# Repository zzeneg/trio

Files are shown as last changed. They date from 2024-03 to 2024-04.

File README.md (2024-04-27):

# trio

Modular unibody keyboard with two VIK modules.

> [!CAUTION]
> This keyboard is designed for minimal vertical spacing (19x16mm). Regular keycaps will not fit, you must print your own - for example my [DES MinY](https://github.com/zzeneg/PseudoMakeMeKeyCapProfiles?tab=readme-ov-file#update-from-zzeneg).
>
> It's created as a cheap prototype to test VIK abilities and modules - all PCBs are under 100x100mm, one-piece case <0.3kg for cheap JLCPCB shipping.
>
> Build process requires a lot of hand-soldering with 0.5mm pitch, you need good tools and experience to do that.
>
> I do not recommend to build it exactly like that, but to use it as inspiration for your projects. Feel free to use and improve KiCad and Fusion 360 source files.

## Features

- **MinY (19x16mm) spacing**
- 36 KS-33 (Gateron Low Profile) keys with hotswap
- central PCB with two independent VIKs, DRV2605L haptic feedback and rotary encoder
- periferal PCBs for keys
- 3D printed case with 1.28" display, Azoteq TPS65 touchpad and 33mm encoder

## Photos

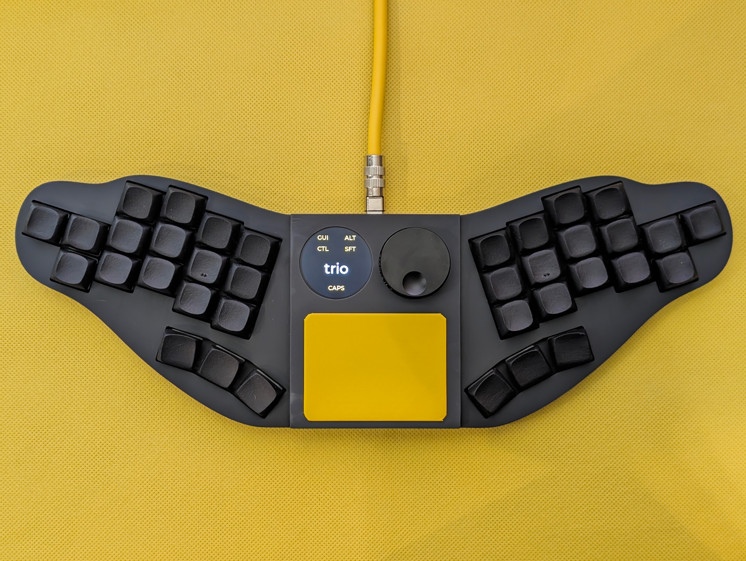
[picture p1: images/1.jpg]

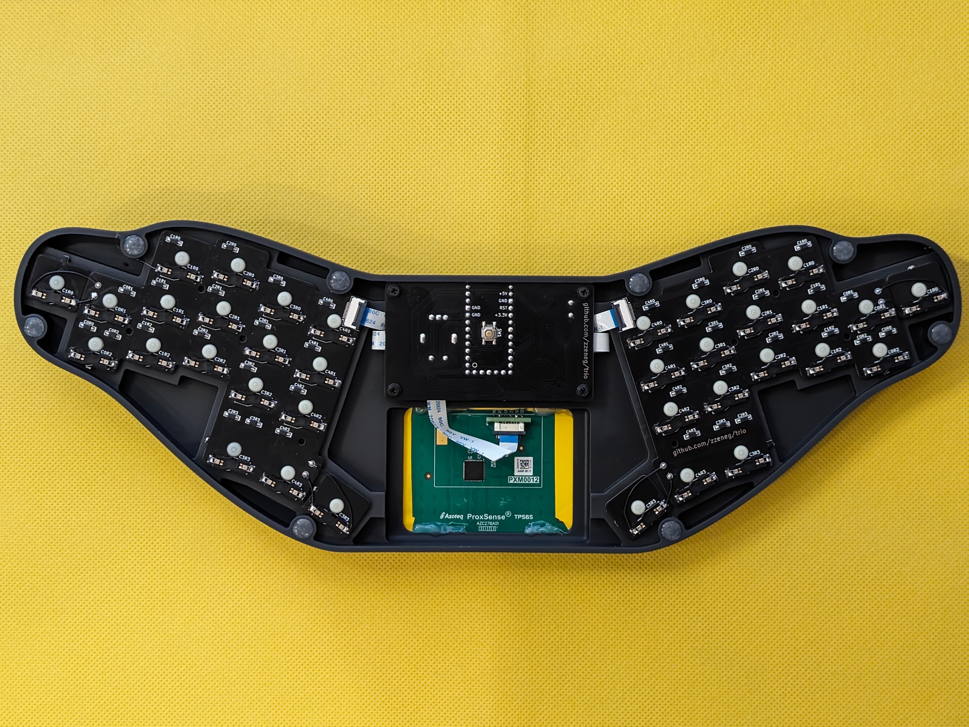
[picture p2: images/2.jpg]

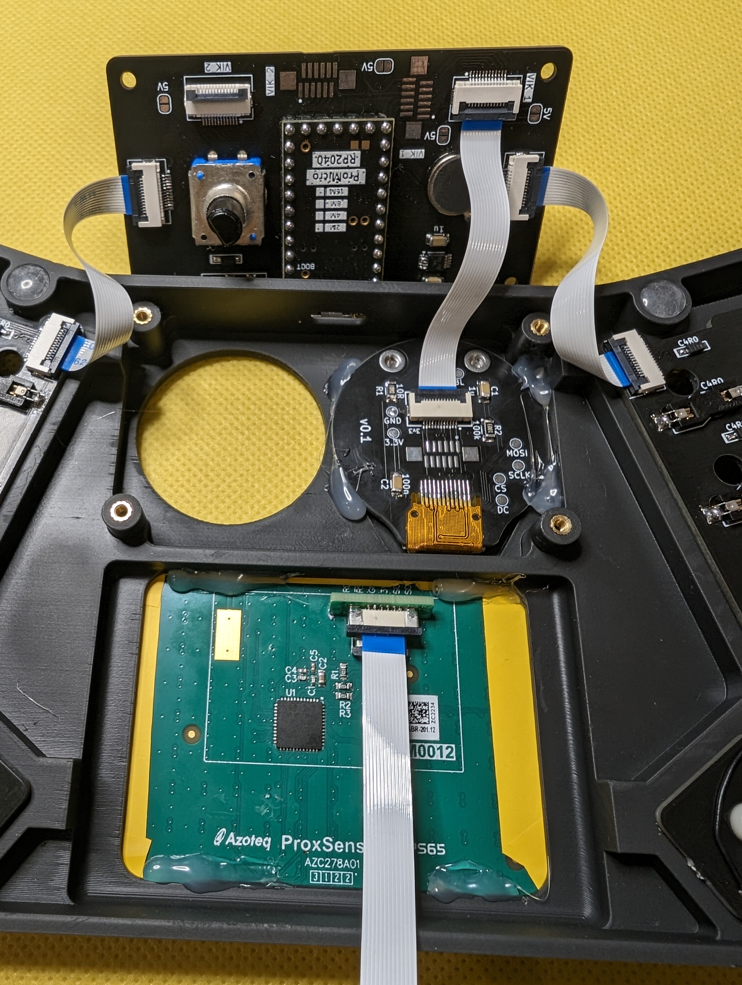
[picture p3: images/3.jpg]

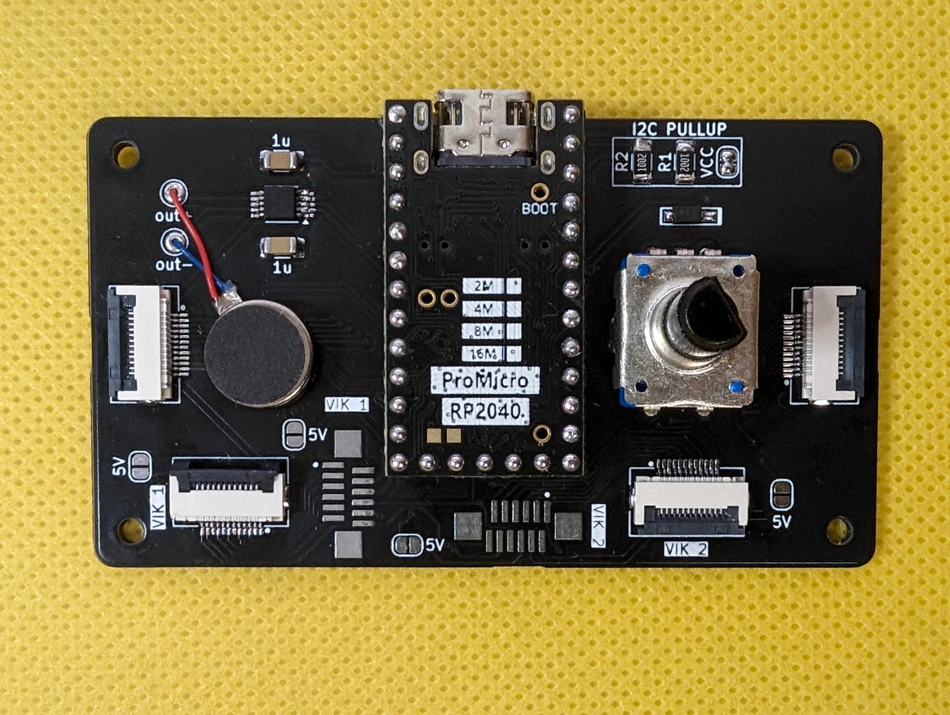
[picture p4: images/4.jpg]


## Gerber files

- [Main PCB](./pcb/production/main.zip)
- [Side PCB](./pcb/production/side.zip)
- Azoteq [VIK adapter](https://github.com/sadekbaroudi/vik/tree/master/pcb/azoteq-tps)
- Display [VIK adapter](https://github.com/zzeneg/vik-display-adapter) - 1.28" round version

## Case files

- [v0.1](./case/main-0.1.stl)
- [v0.2](./case/main-0.1.stl) - higher version, should work but untested

## Firmware

[Companion app](https://github.com/zzeneg/qmk-hid-host) for Raw HID communication. Use `"productId": 2120` for that keyboard.

#### QMK

Please see main `config.h` and `rules.mk` for comments and available options.

- [source code](https://github.com/zzeneg/qmk_firmware/tree/feature/zzeneg/keyboards/trio)
- [pre-compiled files](https://github.com/zzeneg/qmk_firmware/releases/tag/zzeneg)

#### Vial

- [source code](https://github.com/zzeneg/vial-qmk/tree/feature/zzeneg/keyboards/trio)
- [pre-compiled files](https://github.com/zzeneg/vial-qmk/releases/tag/zzeneg)

## Bill of materials

- [PCB](./pcb/production/pcb.zip)
- 36 KS-33 switches
- 36 hotswap sockets for KS-33 switches
- 3D printed case
- Azoteq TPS65 touchpad
- Azoteq [VIK adapter](https://github.com/sadekbaroudi/vik/tree/master/pcb/azoteq-tps)
- Bare 1.28" round [display](https://www.aliexpress.com/item/1005006051175539.html) - **without PCB**
- Display [VIK adapter](https://github.com/zzeneg/vik-display-adapter) - 1.28" round version **+ adapter's BOM**
- Helios-sized (26 GPIOs) [RP2040](https://www.aliexpress.com/item/1005006130019224.html) MCU
- 37 [SMD SOD-123 1N4148](https://www.aliexpress.com/item/1005002882901030.html) diodes
- [Vertical](https://www.aliexpress.com/item/10000000737049.html) and [horizontal](https://www.aliexpress.com/item/4000106123266.html) 12pin FFC/FPC connectors
- 12pin 0.5mm pitch 6cm [FFC cable](https://www.aliexpress.com/item/1005002468369055.html) - **both reverse and forward variants**
- short [EC11 rotary encoder](https://www.aliexpress.com/item/1005002109267228.html)
- 32mm [encoder knob](https://www.aliexpress.com/item/32749414806.html)
- SMD 4x4x1.5mm [push button](https://www.aliexpress.com/item/32802382507.html)
- 4mm [M2 screws with flat head](https://www.aliexpress.com/item/4001248931159.html)
- M2 [heatset inserts](https://www.aliexpress.com/item/1005004624377733.html) - 3mm length, 3.2mm diameter for resin case or 3.5mm for Nylon/PLA
- [7x1.5 legs](https://www.aliexpress.com/item/1005002995402961.html)
- for haptic feedback:
  - DRV2605L motor controller
  - 2 1uF capacitors (SMD 1206 size)
  - 2 4.7kOhm resistors (SMD 1206 size)
  - LRA or ERM [motor](https://docs.qmk.fm/#/feature_haptic_feedback?id=known-supported-hardware)

## Build notes

- side PCBs have two keys that have to be broken off and handwired to correct places (diodes stay on the big part)
- rotary encoder uses GPIO from VIK2, so Azoteq has to be connected to VIK2 port, and display to VIK1. Make sure to bridge solder jumpers on the back.
- cheap ERM motors may not have enough internal resistance, if you motor does not work, try to add 5-10R resistor to it
- see photos for FFC connections

## Development

For proper KiCad setup install my [zzkeeb](https://github.com/zzeneg/zzkeeb/blob/main/README.md#installation) library

## Support

If you like my work and want to support my future designs, please consider [sponsorship](https://github.com/sponsors/zzeneg).

#### Sponsors

Thank you very much for your support!



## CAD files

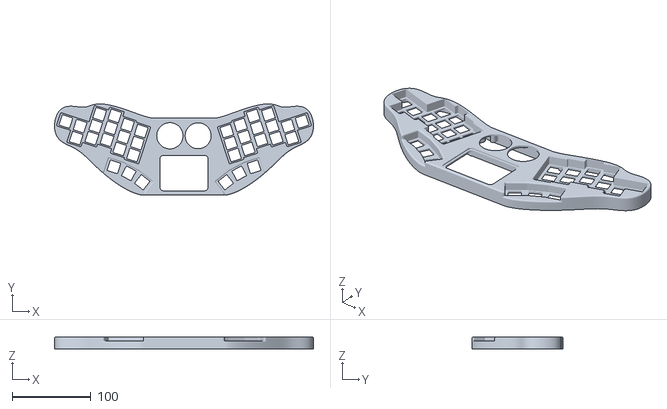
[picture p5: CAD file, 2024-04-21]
case/main-0.2-untested.stl
329.7 x 116.1 x 15.4

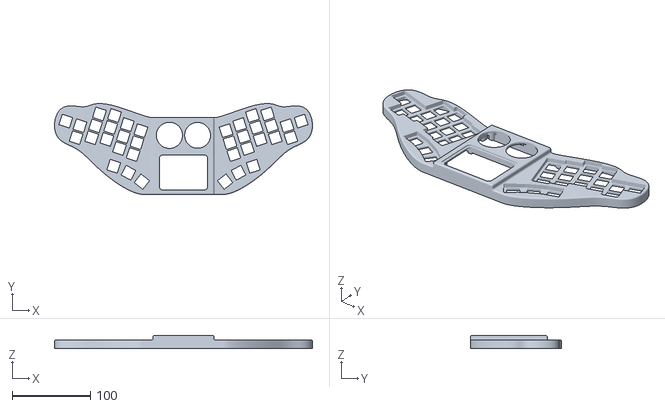
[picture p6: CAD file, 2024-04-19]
case/main-0.1.stl
329.7 x 116.1 x 16.4

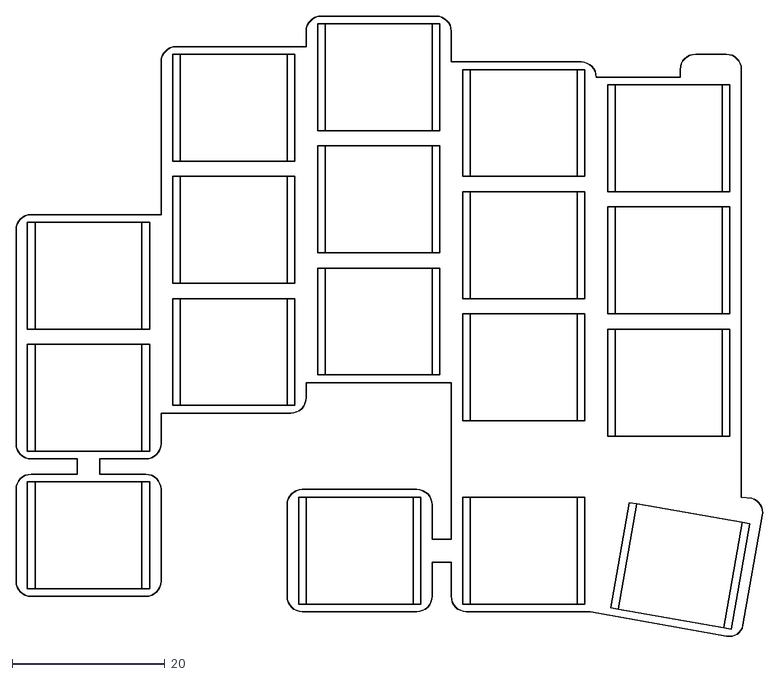
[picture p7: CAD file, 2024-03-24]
pcb/side-Edge_Cuts.dxf
98.0 x 81.3

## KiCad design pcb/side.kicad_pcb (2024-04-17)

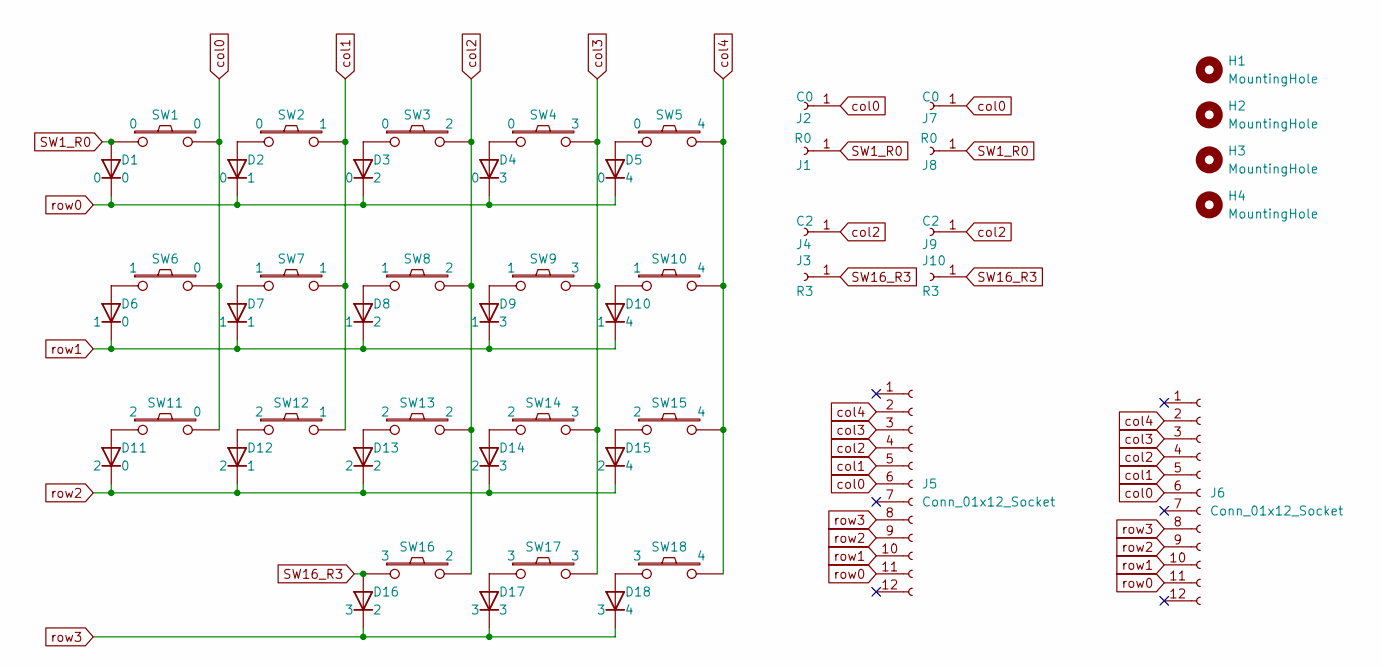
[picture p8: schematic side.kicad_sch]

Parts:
D1, D2, D3, D4, D5, D6, D7, D8, D9, D10, D11, D12, D13, D14, D15, D16, D17, D18: D; Diode_1N4148-SOD123-reversible-flip3d
H1, H2, H3, H4: MountingHole; Hole_M2
J1, J8: R0; TestPoint_THTPad_D1.5mm_Drill0.7mm
J2, J7: C0; TestPoint_THTPad_D1.5mm_Drill0.7mm
J3, J10: R3; TestPoint_THTPad_D1.5mm_Drill0.7mm
J4, J9: C2; TestPoint_THTPad_D1.5mm_Drill0.7mm
J5, J6: Conn_01x12_Socket; Connector_FFC-12pin-0.5mm-horizontal
SW1, SW2, SW3, SW4, SW5, SW6, SW7, SW8, SW9, SW10, SW11, SW12, SW13, SW14, SW15, SW16, SW17, SW18: Switch; Switch_KS-miny-reversible-hotswap-south

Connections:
unnamed: D2.2 (A), SW2.1
unnamed: D3.2 (A), SW3.1
unnamed: D4.2 (A), SW4.1
unnamed: D5.2 (A), SW5.1
unnamed: D6.2 (A), SW6.1
unnamed: D7.2 (A), SW7.1
unnamed: D8.2 (A), SW8.1
unnamed: D9.2 (A), SW9.1
unnamed: D10.2 (A), SW10.1
unnamed: D11.2 (A), SW11.1
unnamed: D12.2 (A), SW12.1
unnamed: D13.2 (A), SW13.1
unnamed: D14.2 (A), SW14.1
unnamed: D15.2 (A), SW15.1
unnamed: D17.2 (A), SW17.1
unnamed: D18.2 (A), SW18.1
SW1_R0: D1.2 (A), J1.1, J8.1, SW1.1
SW16_R3: D16.2 (A), J3.1, J10.1, SW16.1
col0: J2.1, J5.6, J6.6, J7.1, SW1.2, SW6.2, SW11.2
col1: J5.5, J6.5, SW2.2, SW7.2, SW12.2
col2: J4.1, J5.4, J6.4, J9.1, SW3.2, SW8.2, SW13.2, SW16.2
col3: J5.3, J6.3, SW4.2, SW9.2, SW14.2, SW17.2
col4: J5.2, J6.2, SW5.2, SW10.2, SW15.2, SW18.2
row0: D1.1 (K), D2.1 (K), D3.1 (K), D4.1 (K), D5.1 (K), J5.11, J6.11
row1: D6.1 (K), D7.1 (K), D8.1 (K), D9.1 (K), D10.1 (K), J5.10, J6.10
row2: D11.1 (K), D12.1 (K), D13.1 (K), D14.1 (K), D15.1 (K), J5.9, J6.9
row3: D16.1 (K), D17.1 (K), D18.1 (K), J5.8, J6.8

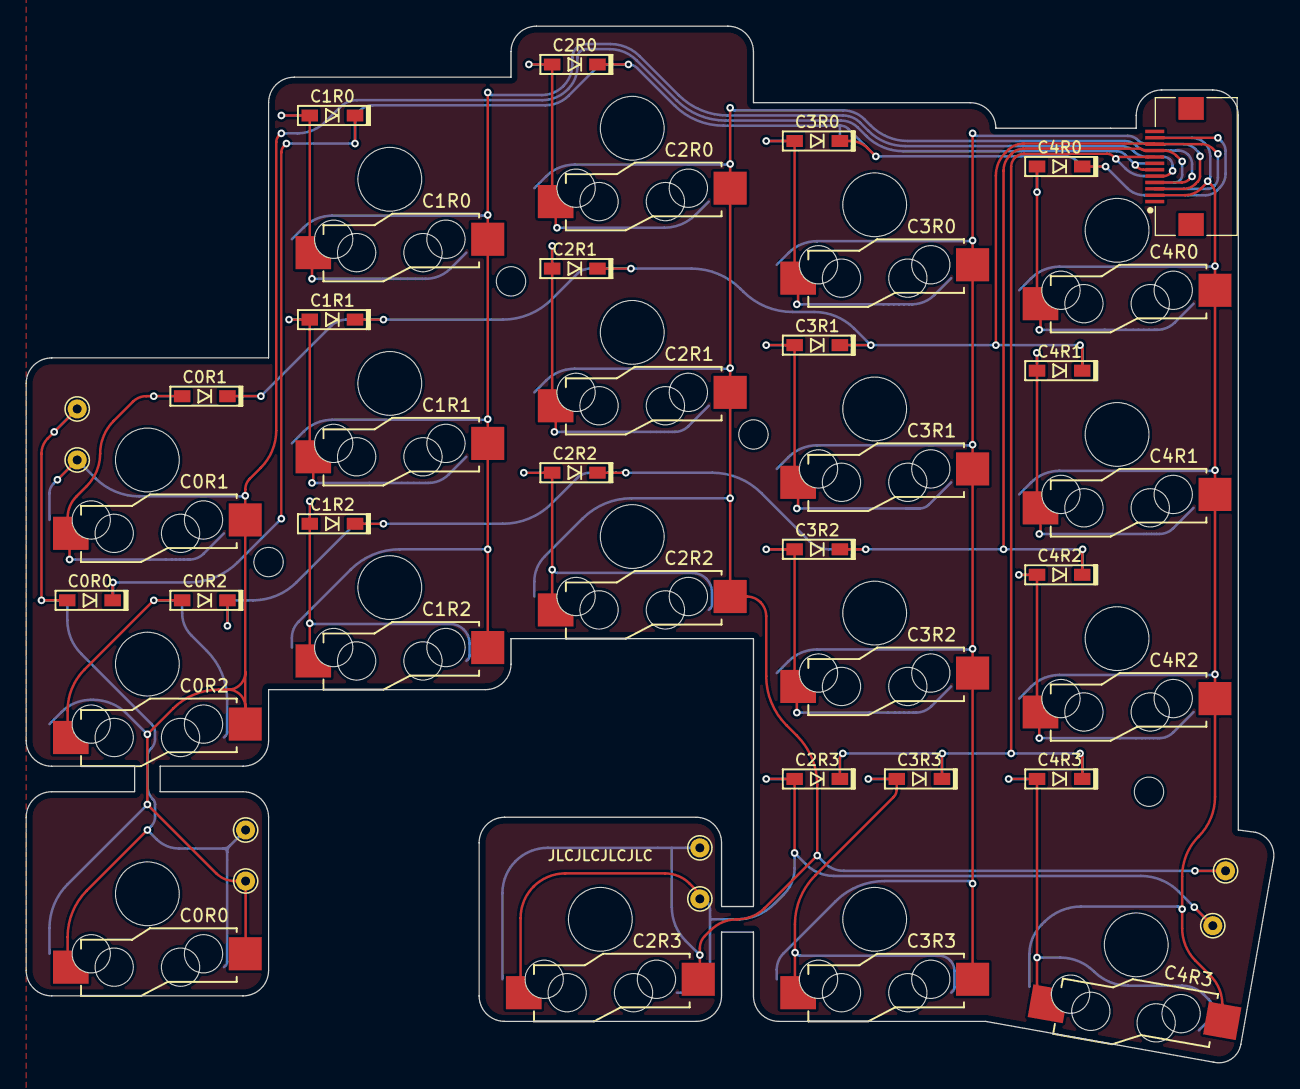
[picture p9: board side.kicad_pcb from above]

Board: 2 copper layers, 97.8 x 81.2 mm, 50 parts (1 on the bottom side), 27 nets.

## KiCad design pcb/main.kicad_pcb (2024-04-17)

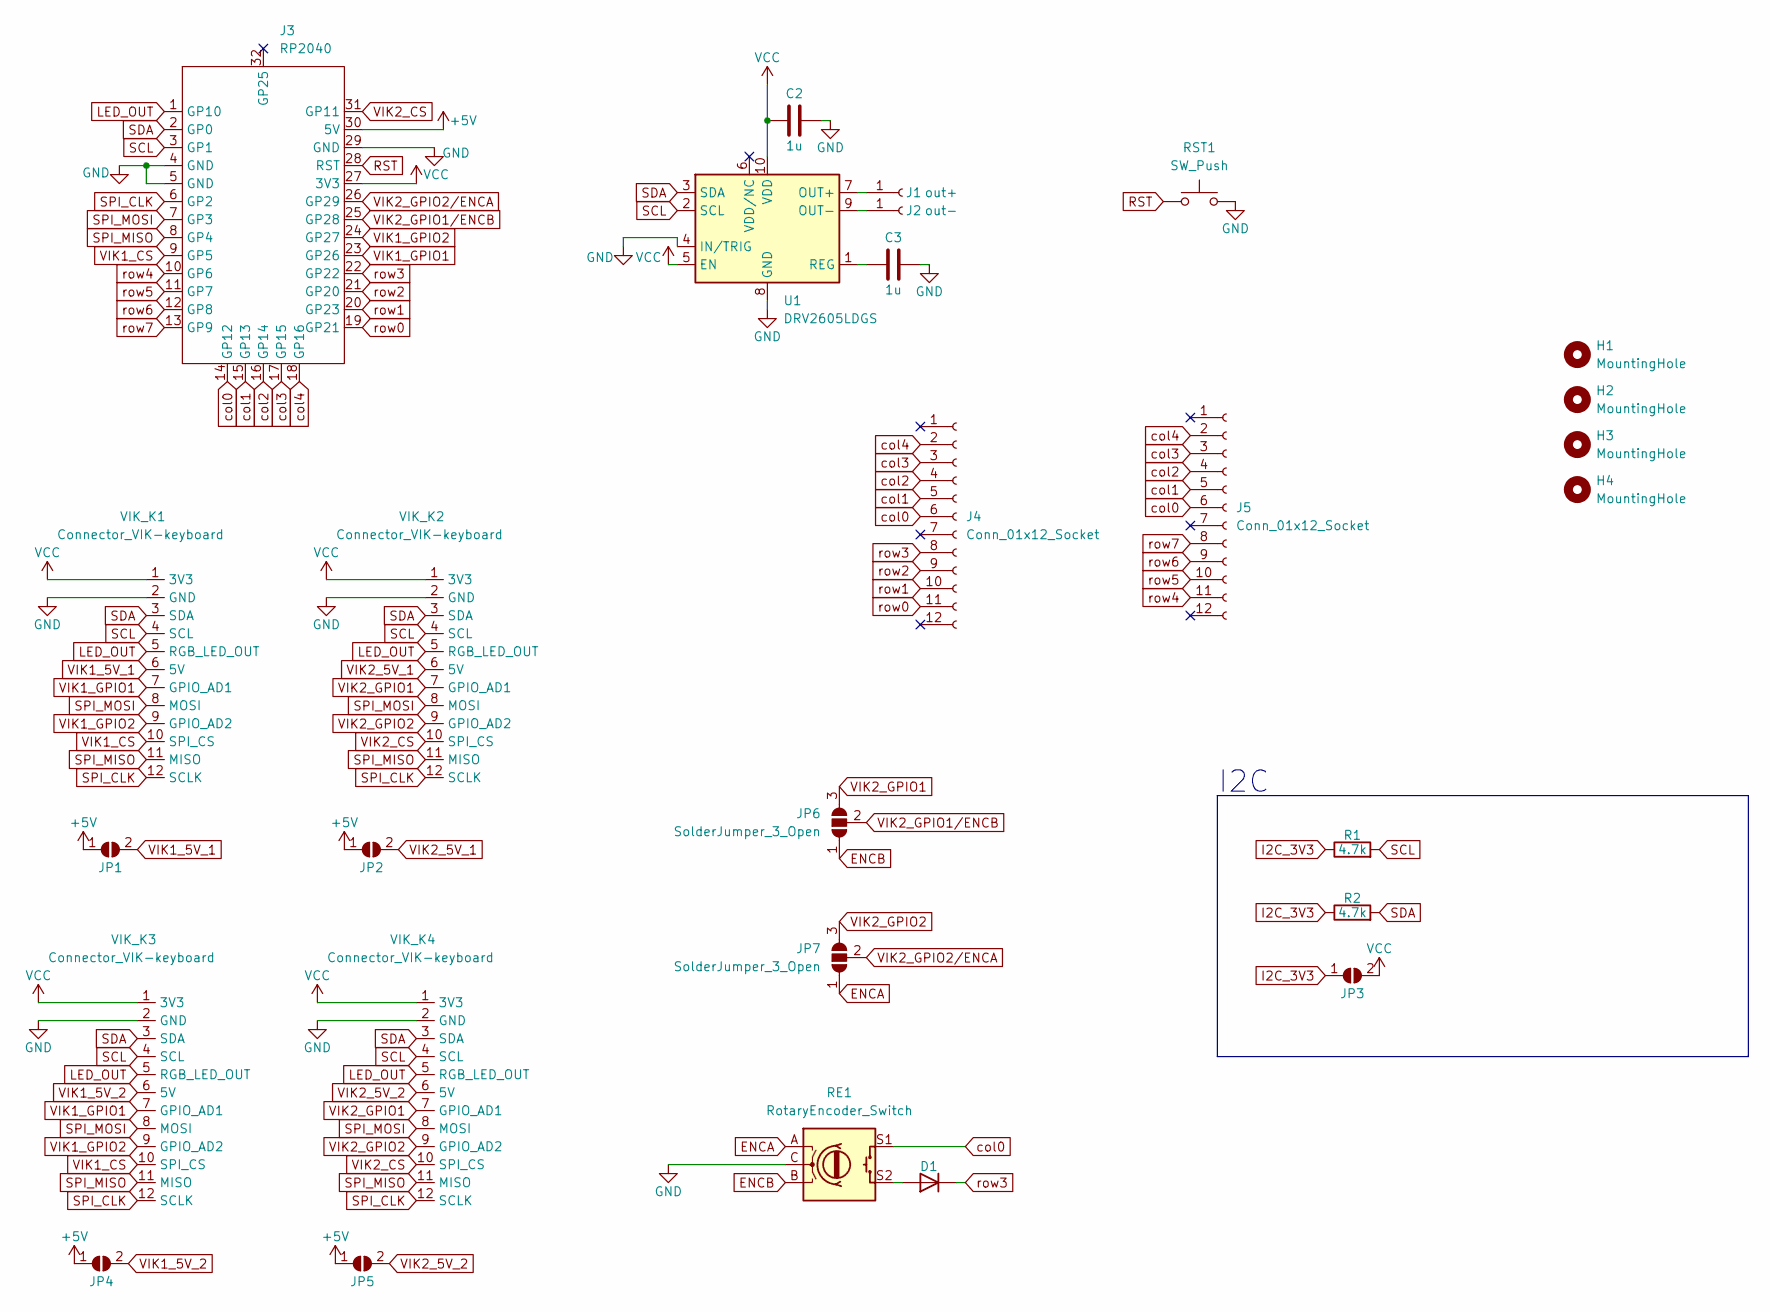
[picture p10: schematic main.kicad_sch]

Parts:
C2, C3: 1u; C_1206_3216Metric
D1: D; Diode_1N4148-SOD123
H1, H2, H3, H4: MountingHole; Hole_M2
J1: out+; TestPoint_THTPad_D2.0mm_Drill1.0mm
J2: out-; TestPoint_THTPad_D2.0mm_Drill1.0mm
J3: RP2040; MCU_rp2040-helios
J4, J5: Conn_01x12_Socket; Connector_FFC-12pin-0.5mm-horizontal
JP1, JP2, JP4, JP5: 5V; SolderJumper-2_P1.3mm_Open_RoundedPad1.0x1.5mm
JP3: VCC; SolderJumper-2_P1.3mm_Open_RoundedPad1.0x1.5mm
JP6, JP7: SolderJumper_3_Open; SolderJumper-3_P1.3mm_Open_Pad1.0x1.5mm
R1, R2: 4.7k; R_1206_3216Metric
RE1: RotaryEncoder_Switch; RotaryEncoder_EC11
RST1: SW_Push; Button_SW_SPST_SKQG_WithoutStem
U1: DRV2605LDGS; VSSOP-10_3x3mm_P0.5mm
VIK_K1, VIK_K2: Connector_VIK-keyboard; Connector_VIK-horizontal-keyboard
VIK_K3, VIK_K4: Connector_VIK-keyboard; Connector_VIK-vertical-keyboard

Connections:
+5V: J3.30 (5V), JP1.1 (A), JP2.1 (A), JP4.1 (A), JP5.1 (A)
ENCA: JP7.1 (A), RE1.A
ENCB: JP6.1 (A), RE1.B
GND: C2.2, C3.2, J3.4 (GND), J3.5 (GND), J3.29 (GND), RE1.C, RST1.2, U1.4 (IN/TRIG), U1.8 (GND), VIK_K1.2 (GND), VIK_K2.2 (GND), VIK_K3.2 (GND), VIK_K4.2 (GND)
I2C_3V3: JP3.1 (A), R1.1, R2.1
LED_OUT: J3.1 (GP10), VIK_K1.5 (RGB_LED_OUT), VIK_K2.5 (RGB_LED_OUT), VIK_K3.5 (RGB_LED_OUT), VIK_K4.5 (RGB_LED_OUT)
unnamed: D1.2 (A), RE1.S2
unnamed: J1.1, U1.7 (OUT+)
unnamed: J2.1, U1.9 (OUT-)
unnamed: C3.1, U1.1 (REG)
RST: J3.28 (RST), RST1.1
SCL: J3.3 (GP1), R1.2, U1.2 (SCL), VIK_K1.4 (SCL), VIK_K2.4 (SCL), VIK_K3.4 (SCL), VIK_K4.4 (SCL)
SDA: J3.2 (GP0), R2.2, U1.3 (SDA), VIK_K1.3 (SDA), VIK_K2.3 (SDA), VIK_K3.3 (SDA), VIK_K4.3 (SDA)
SPI_CLK: J3.6 (GP2), VIK_K1.12 (SCLK), VIK_K2.12 (SCLK), VIK_K3.12 (SCLK), VIK_K4.12 (SCLK)
SPI_MISO: J3.8 (GP4), VIK_K1.11 (MISO), VIK_K2.11 (MISO), VIK_K3.11 (MISO), VIK_K4.11 (MISO)
SPI_MOSI: J3.7 (GP3), VIK_K1.8 (MOSI), VIK_K2.8 (MOSI), VIK_K3.8 (MOSI), VIK_K4.8 (MOSI)
VCC: C2.1, J3.27 (3V3), JP3.2 (B), U1.5 (EN), U1.10 (VDD), VIK_K1.1 (3V3), VIK_K2.1 (3V3), VIK_K3.1 (3V3), VIK_K4.1 (3V3)
VIK1_5V_1: JP1.2 (B), VIK_K1.6 (5V)
VIK1_5V_2: JP4.2 (B), VIK_K3.6 (5V)
VIK1_CS: J3.9 (GP5), VIK_K1.10 (SPI_CS), VIK_K3.10 (SPI_CS)
VIK1_GPIO1: J3.23 (GP26), VIK_K1.7 (GPIO_AD1), VIK_K3.7 (GPIO_AD1)
VIK1_GPIO2: J3.24 (GP27), VIK_K1.9 (GPIO_AD2), VIK_K3.9 (GPIO_AD2)
VIK2_5V_1: JP2.2 (B), VIK_K2.6 (5V)
VIK2_5V_2: JP5.2 (B), VIK_K4.6 (5V)
VIK2_CS: J3.31 (GP11), VIK_K2.10 (SPI_CS), VIK_K4.10 (SPI_CS)
VIK2_GPIO1: JP6.3 (B), VIK_K2.7 (GPIO_AD1), VIK_K4.7 (GPIO_AD1)
VIK2_GPIO1/ENCB: J3.25 (GP28), JP6.2 (C)
VIK2_GPIO2: JP7.3 (B), VIK_K2.9 (GPIO_AD2), VIK_K4.9 (GPIO_AD2)
VIK2_GPIO2/ENCA: J3.26 (GP29), JP7.2 (C)
col0: J3.14 (GP12), J4.6, J5.6, RE1.S1
col1: J3.15 (GP13), J4.5, J5.5
col2: J3.16 (GP14), J4.4, J5.4
col3: J3.17 (GP15), J4.3, J5.3
col4: J3.18 (GP16), J4.2, J5.2
row0: J3.19 (GP21), J4.11
row1: J3.20 (GP23), J4.10
row2: J3.21 (GP20), J4.9
row3: D1.1 (K), J3.22 (GP22), J4.8
row4: J3.10 (GP6), J5.11
row5: J3.11 (GP7), J5.10
row6: J3.12 (GP8), J5.9
row7: J3.13 (GP9), J5.8

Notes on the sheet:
I2C

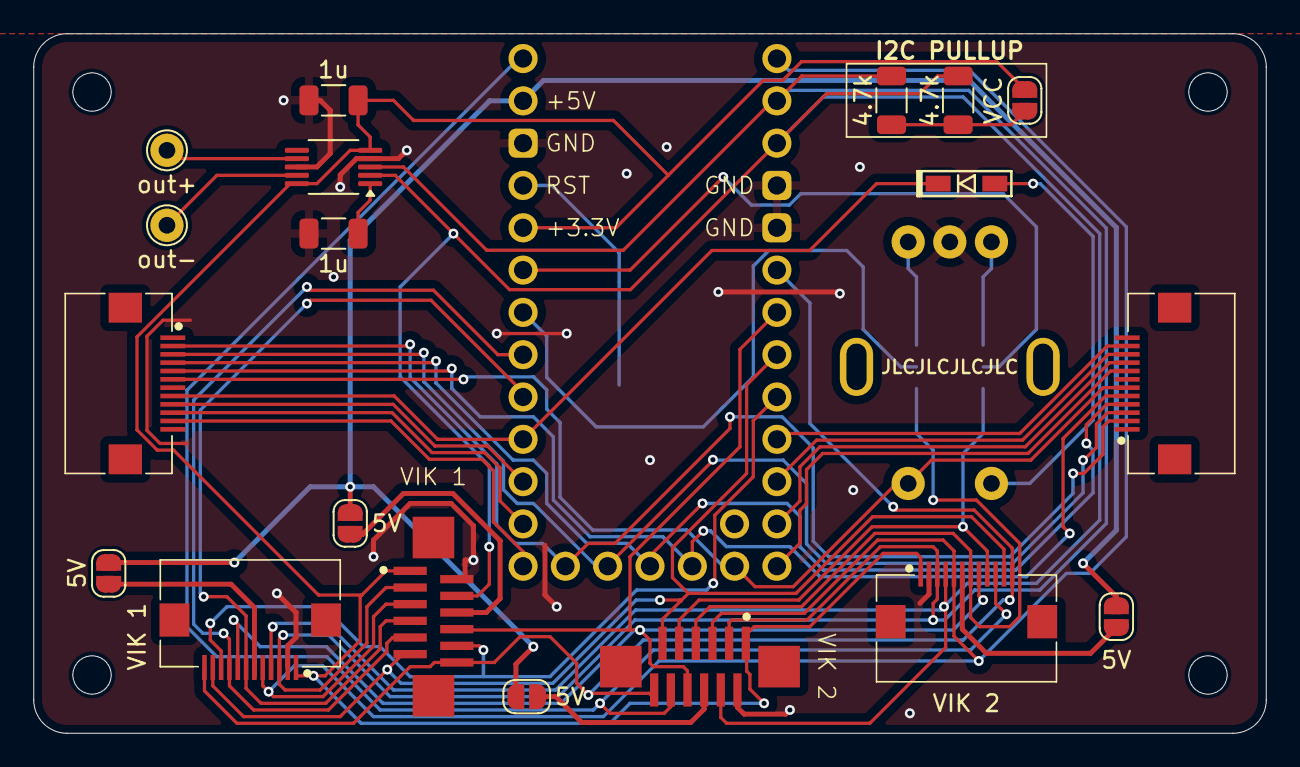
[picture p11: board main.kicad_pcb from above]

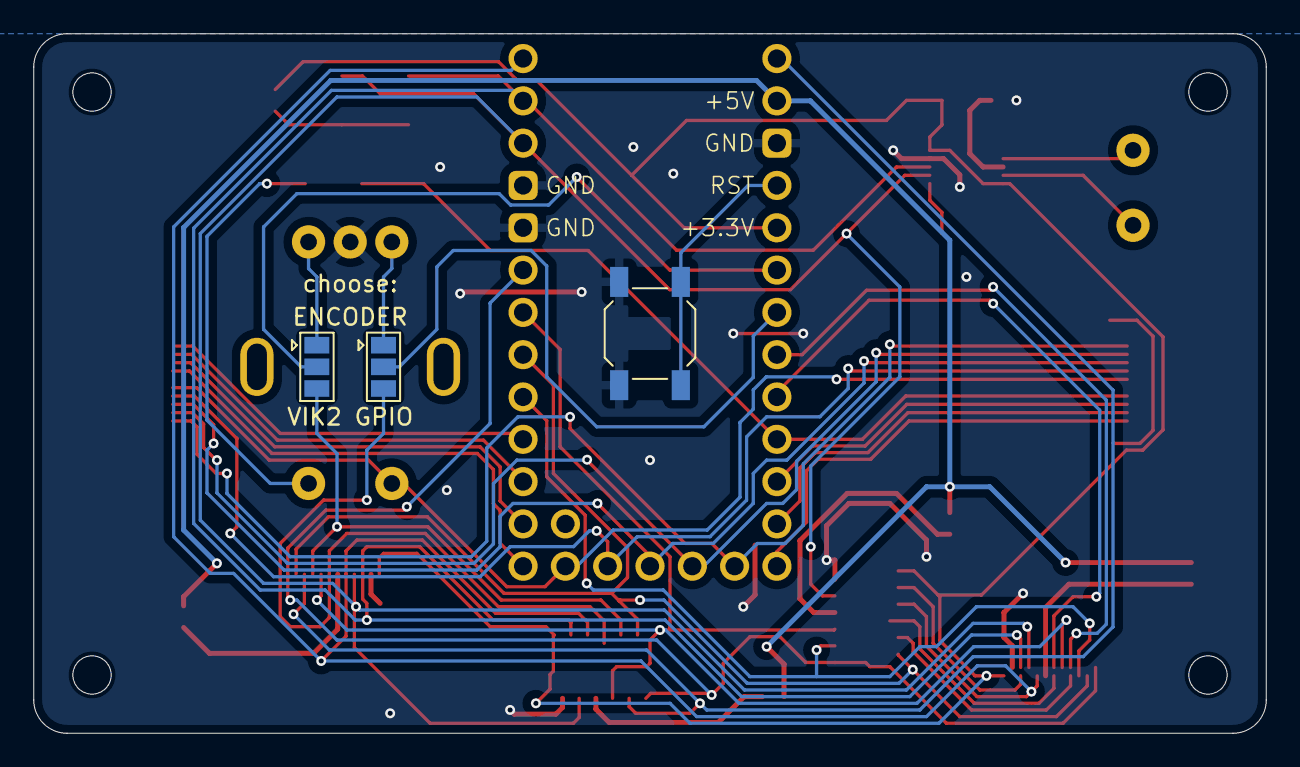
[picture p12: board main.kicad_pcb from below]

Board: 2 copper layers, 74.0 x 42.0 mm, 28 parts (4 on the bottom side), 42 nets.

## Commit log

2024-03-24 add side pcb
    [side-Edge_Cuts.dxf, side.kicad_pcb, side.kicad_sch]
2024-03-24 add main pcb
    [main.kicad_pcb, main.kicad_sch]
2024-03-24 add case
    [main.stl]
2024-03-26 small updates
    [main.kicad_pcb, main.stl, side.kicad_pcb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]
2024-04-14 fix case
    [main.stl]
2024-04-17 jumpers for VIK GPIO, small side updates
    [main.kicad_pcb, main.kicad_sch, main.stl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]
2024-04-19 update case
    [main-0.1.stl, main-0.2-untested.stl, main.stl]
2024-04-21 add readme
    [main-0.2-untested.stl]
